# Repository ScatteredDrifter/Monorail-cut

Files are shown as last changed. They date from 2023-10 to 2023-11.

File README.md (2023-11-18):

# Monorail V2

This board adapts the original **Monorail V²** however some fundamental changes were made to fit into a different case by **M4NU**.

## Current status:

>Prototypes were ordered and are functioning. 

- + Encoder works 
- + VIAL firmware works 
- + LED-Backlight works
- - misconfigured stabilizer orientation. This has been fixed in 9eb0997

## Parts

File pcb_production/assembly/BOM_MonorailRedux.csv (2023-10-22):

Comment | Designator | Footprint | LCSC
10u | C1,C2,C4 | Capacitor_SMD:C_0402_1005Metric | C315248
0.1uF | LCSC: C3011705 | C13,C14,C15,C16,C17,C18,C19,C20 | Capacitor_SMD:C_0603_1608Metric | C3011705
1u | C3,C5 | Capacitor_SMD:C_0402_1005Metric | C107372
30p | C6,C27 | Capacitor_SMD:C_0402_1005Metric | C1570
100n | C7,C8,C21,C22,C23,C25,C26,C28 | Capacitor_SMD:C_0402_1005Metric | C60474
BAV70 | D1,D2,D3,D4,D5,D6,D7,D8,D9,D10,D11,D12,D13,D14,D15,D16,D17,D18,D19,D20,D21,D22 | Package_TO_SOT_SMD:SOT-23 | C68978
WS2812B | D59,D60,D61,D62,D63,D64,D65,D66,D67 | WS2812B:WS2812B_data-bridgeable
500mA | F1 | Fuse:Fuse_1206_3216Metric | C69688
MountingHole_Pad | H1 | kicad:Minivan-reference
Conn_01x02_Male | J1,J2,J3 | Connector_PinHeader_2.54mm:PinHeader_1x02_P2.54mm_Vertical
Conn_01x02_Male | J4 | Connector_PinSocket_2.54mm:PinSocket_1x02_P2.54mm_Vertical
USB_C_Receptacle_USB2.0 | J6 | Connector_USB:USB_C_Receptacle_HRO_TYPE-C-31-M-12 | C165948
Conn_01x04_Male | J8 | Connector_PinHeader_2.54mm:PinHeader_1x04_P2.54mm_Vertical
Conn_01x03_Male | J9 | Connector_PinHeader_2.54mm:PinHeader_1x03_P2.54mm_Vertical
SolderJumper_2_Bridged | JP1 | Jumper:SolderJumper-2_P1.3mm_Bridged2Bar_Pad1.0x1.5mm
MX-NoLED | MX1,MX2,MX7,MX8,MX9,MX10,MX11,MX12,MX13,MX14,MX15,MX16,MX17,MX18,MX19,MX20,MX21,MX22,MX23,MX24,MX25,MX26,MX27,MX28,MX29,MX30,MX31,MX32,MX33,MX34,MX35,MX36,MX37,MX38,MX39,MX40,MX41,MX42,MX43,MX45,MX46,MX47,MX48,MX49,MX52,MX53,MX54,MX57,MX58 | marbastlib-mx:SW_MX_HS_1u_NOREF
MX-NoLED | MX3 | marbastlib-mx:SW_MX_1u
1k | R12,R14 | Resistor_SMD:R_0402_1005Metric | C11702
-10k | R13 | Resistor_SMD:R_0603_1608Metric | C98220
5.1k | R2,R4,R5 | Resistor_SMD:R_0603_1608Metric | C23186
27 | R6,R7 | Resistor_SMD:R_0402_1005Metric | C138021
RotaryEncoder_Switch | SW3 | marbastlib-various:ROT_Alps_EC11E-Switch
Conn_01x03_Female | SWD1 | Connector_PinHeader_2.54mm:PinHeader_1x03_P2.54mm_Vertical
SW_SPST | SWR1,SWR2 | Keebio-Parts:SW_SPST_TL3342 | C2886894
SRV05-4 | U1 | Package_TO_SOT_SMD:SOT-23-6 | C85364
XC6206PxxxMR | U2 | Package_TO_SOT_SMD:SOT-23 | C5446
RP2040TR7 | U3 | cipulot_kicad_parts:RP2040-QFN-56 | C2040
W25Q128JVS | U4 | Package_SO:SOIC-8_5.23x5.23mm_P1.27mm | C97521
Crystal_GND24_Small | Y1 | Crystal:Crystal_SMD_3225-4Pin_3.2x2.5mm | C9002

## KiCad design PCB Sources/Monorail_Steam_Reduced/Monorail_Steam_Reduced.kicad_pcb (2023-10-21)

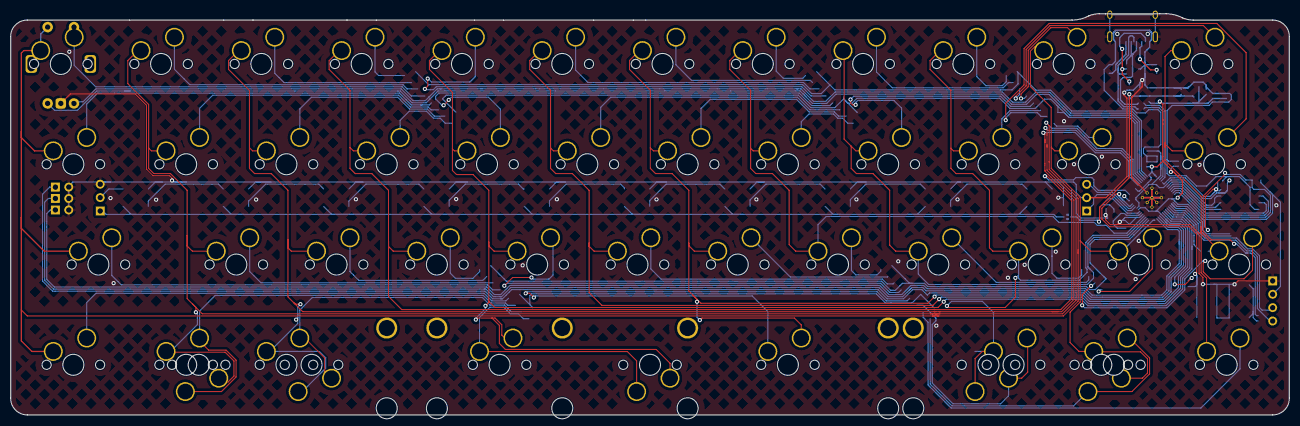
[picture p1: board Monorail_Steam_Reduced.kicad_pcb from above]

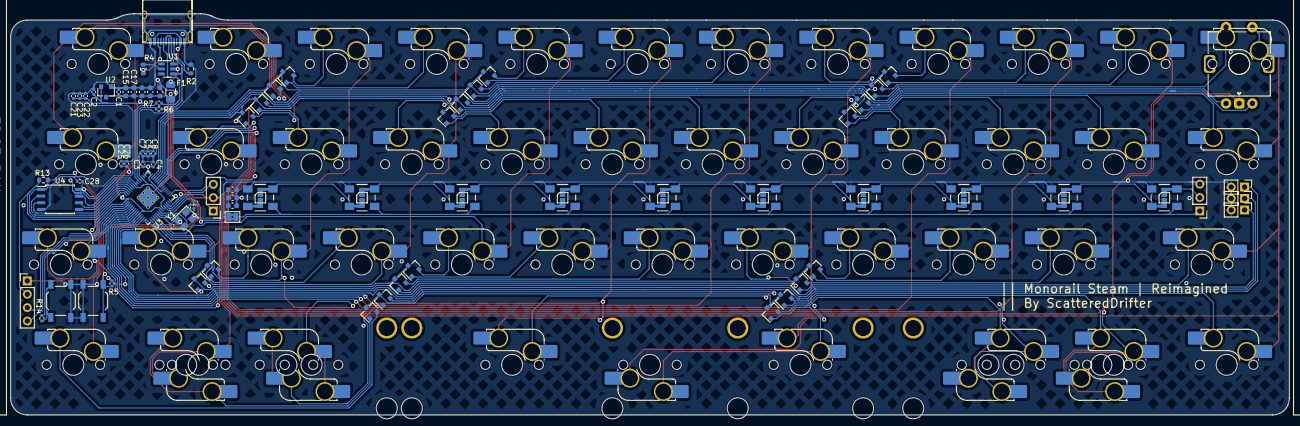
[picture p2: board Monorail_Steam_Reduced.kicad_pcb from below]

Board: 2 copper layers, 242.9 x 76.2 mm, 129 parts (129 on the bottom side), 102 nets.

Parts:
C1, C2, C4: 10u; C_0402_1005Metric
C3, C5: 1u; C_0402_1005Metric
C6, C27: 30p; C_0402_1005Metric
C7, C8, C21, C22, C23, C25, C26, C28: 100n; C_0402_1005Metric
C13, C14, C15, C16, C17, C18, C19, C20: 0.1uF; C_0603_1608Metric
D1, D2, D3, D4, D5, D6, D7, D8, D9, D10, D11, D12, D13, D14, D15, D16, D17, D18, D19, D20, D21, D22: BAV70; SOT-23
D56, D59, D60, D61, D62, D63, D64, D65, D66, D67: WS2812B; WS2812B_data-bridgeable
F1: 500mA; Fuse_1206_3216Metric
J1, J2, J3: Conn_01x02_Male; PinHeader_1x02_P2.54mm_Vertical
J6: USB_C_Receptacle_USB2.0; USB_C_Receptacle_HRO_TYPE-C-31-M-12
J8: Conn_01x04_Male; PinHeader_1x04_P2.54mm_Vertical
J9: Conn_01x03_Male; PinHeader_1x03_P2.54mm_Vertical
JP1: SolderJumper_2_Bridged; SolderJumper-2_P1.3mm_Bridged2Bar_Pad1.0x1.5mm
MX1, MX2, MX7, MX8, MX9, MX10, MX11, MX12, MX13, MX14, MX15, MX16, MX17, MX18, MX19, MX20, MX21, MX22, MX23, MX24, MX25, MX26, MX27, MX28, MX29, MX30, MX31, MX32, MX33, MX34, MX35, MX36, MX37, MX38, MX39, MX40, MX41, MX42, MX43, MX45, MX46, MX47, MX48, MX49, MX52, MX53, MX54, MX57, MX58: MX-NoLED; SW_MX_HS_1u_NOREF
R2, R4: 5.1k; R_0603_1608Metric
R5: 5.1k; R_0402_1005Metric
R6, R7: 27; R_0402_1005Metric
R12, R14: 1k; R_0402_1005Metric
R13: -10k; R_0603_1608Metric
SW3: RotaryEncoder_Switch; ROT_Alps_EC11E-Switch
SWD1: Conn_01x03_Female; PinHeader_1x03_P2.54mm_Vertical
SWR1, SWR2: SW_SPST; SW_SPST_TL3342
U1: SRV05-4; SOT-23-6
U2: XC6206PxxxMR; SOT-23
U3: RP2040TR7; RP2040-QFN-56
U4: W25Q128JVS; SOIC-8_5.23x5.23mm_P1.27mm
Y1: Crystal_GND24_Small; Crystal_SMD_3225-4Pin_3.2x2.5mm

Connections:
+1V1: C5.1, C7.1, C8.1, U3.23 (DVDD), U3.45 (VREG_VOUT), U3.50 (DVDD)
+3V3: C2.1, C3.1, C4.1, C21.1, C22.1, C23.1, C25.1, C26.1, C28.1, J8.2, R5.1, R13.1, U2.2 (VO), U3.1 (IOVDD), U3.10 (IOVDD), U3.22 (IOVDD), U3.33 (IOVDD), U3.42 (IOVDD), U3.43 (ADC_AVDD), U3.44 (VREG_VIN), U3.48 (USB_VDD), U3.49 (IOVDD), U4.8 (VCC)
+5V: C1.1, C13.1, C14.1, C15.1, C16.1, C17.1, C18.1, C19.1, C20.1, F1.1, JP1.1 (A), U2.3 (VI)
+5VD: D56.1 (VDD), D59.1 (VDD), D60.1 (VDD), D61.1 (VDD), D62.1 (VDD), D63.1 (VDD), D64.1 (VDD), D65.1 (VDD), D66.1 (VDD), D67.1 (VDD), J9.1, JP1.2 (B)
COL0: MX7.1 (COL), MX19.1 (COL), MX31.1 (COL), MX46.1 (COL), SW3.S1, U3.37 (GPIO25)
COL1: MX2.1 (COL), MX8.1 (COL), MX20.1 (COL), MX32.1 (COL), MX52.1 (COL), U3.36 (GPIO24)
COL2: MX9.1 (COL), MX21.1 (COL), MX33.1 (COL), MX47.1 (COL), MX53.2 (ROW), U3.35 (GPIO23)
COL3: MX10.1 (COL), MX22.1 (COL), MX34.1 (COL), U3.29 (GPIO18)
COL4: MX11.1 (COL), MX23.1 (COL), MX35.1 (COL), MX43.1 (COL), MX45.2 (ROW), U3.7 (GPIO5)
COL5: MX12.1 (COL), MX24.1 (COL), MX36.1 (COL), U3.8 (GPIO6)
COL6: MX13.1 (COL), MX25.1 (COL), MX37.1 (COL), MX58.2 (ROW), U3.9 (GPIO7)
COL7: MX14.1 (COL), MX26.1 (COL), MX38.1 (COL), U3.18 (GPIO15)
COL8: MX15.1 (COL), MX27.1 (COL), MX39.1 (COL), U3.16 (GPIO13)
COL9: MX16.1 (COL), MX28.1 (COL), MX40.1 (COL), MX49.2 (ROW), MX54.1 (COL), U3.17 (GPIO14)
COL10: MX1.1 (COL), MX17.1 (COL), MX29.1 (COL), MX41.1 (COL), MX57.1 (COL), U3.14 (GPIO11)
COL11: MX18.1 (COL), MX30.1 (COL), MX42.1 (COL), MX48.1 (COL), U3.6 (GPIO4)
D+: J6.A6 (D+), J6.B6 (D+), R7.2, U1.6 (IO4)
D-: J6.A7 (D-), J6.B7 (D-), R6.2, U1.4 (IO3)
ENCA: SW3.B, U3.39 (GPIO27/ADC1)
ENCB: SW3.A, U3.40 (GPIO28/ADC2)
ENC_ROW: D1.1 (A), MX7.2 (ROW), SW3.S2
GND: C1.2, C2.2, C3.2, C4.2, C5.2, C6.1, C7.2, C8.2, C13.2, C14.2, C15.2, C16.2, C17.2, C18.2, C19.2, C20.2, C21.2, C22.2, C23.2, C25.2, C26.2, C27.2, C28.2, D56.3 (VSS), D59.3 (VSS), D60.3 (VSS), D61.3 (VSS), D62.3 (VSS), D63.3 (VSS), D64.3 (VSS), D65.3 (VSS), D66.3 (VSS), D67.3 (VSS), J1.2, J2.2, J3.2, J6.A1 (GND), J6.A12 (GND), J6.B1 (GND), J6.B12 (GND), J6.S1 (SHIELD), J8.1, J9.3, R2.1, R4.1, SW3.C, SWD1.2, SWR1.1 (A), SWR2.1 (A), U1.2 (VN), U2.1 (GND), U3.19 (TESTEN), U3.57 (GND), U4.4 (GND), Y1.2, Y1.4
LED1: J1.1, U3.13 (GPIO10)
LED2: J2.1, U3.11 (GPIO8)
LED3: J3.1, U3.12 (GPIO9)
unnamed: C6.2, R12.1, Y1.1
unnamed: D56.4 (DIN), D64.2 (DOUT)
unnamed: D59.2 (DOUT), D60.4 (DIN)
unnamed: D60.2 (DOUT), D61.4 (DIN)
unnamed: D61.2 (DOUT), D62.4 (DIN)
unnamed: D62.2 (DOUT), D63.4 (DIN)
unnamed: D63.2 (DOUT), D67.4 (DIN)
unnamed: D64.4 (DIN), D65.2 (DOUT)
unnamed: D65.4 (DIN), D66.2 (DOUT)
unnamed: D66.4 (DIN), D67.2 (DOUT)
unnamed: J6.A5 (CC1), R2.2
unnamed: J6.B5 (CC2), R4.2
unnamed: D21.1 (A), MX1.2 (ROW), MX57.2 (ROW)
unnamed: D19.1 (A), MX2.2 (ROW), MX52.2 (ROW)
unnamed: D1.2 (A), MX8.2 (ROW)
unnamed: D2.1 (A), MX9.2 (ROW)
unnamed: D2.2 (A), MX10.2 (ROW)
unnamed: D3.1 (A), MX11.2 (ROW)
unnamed: D3.2 (A), MX12.2 (ROW)
unnamed: D4.1 (A), MX13.2 (ROW)
unnamed: D4.2 (A), MX14.2 (ROW)
unnamed: D5.1 (A), MX15.2 (ROW)
unnamed: D5.2 (A), MX16.2 (ROW)
unnamed: D6.1 (A), MX17.2 (ROW)
unnamed: D6.2 (A), MX18.2 (ROW)
unnamed: D7.2 (A), MX19.2 (ROW)
unnamed: D7.1 (A), MX20.2 (ROW)
unnamed: D8.2 (A), MX21.2 (ROW)
unnamed: D8.1 (A), MX22.2 (ROW)
unnamed: D13.2 (A), MX23.2 (ROW)
unnamed: D13.1 (A), MX24.2 (ROW)
unnamed: D14.2 (A), MX25.2 (ROW)
unnamed: D14.1 (A), MX26.2 (ROW)
unnamed: D15.2 (A), MX27.2 (ROW)
unnamed: D15.1 (A), MX28.2 (ROW)
unnamed: D18.1 (A), MX29.2 (ROW)
unnamed: D18.2 (A), MX30.2 (ROW)
unnamed: D9.1 (A), MX31.2 (ROW)
unnamed: D9.2 (A), MX32.2 (ROW)
unnamed: D10.1 (A), MX33.2 (ROW)
unnamed: D10.2 (A), MX34.2 (ROW)
unnamed: D11.1 (A), MX35.2 (ROW)
unnamed: D11.2 (A), MX36.2 (ROW)
unnamed: D12.1 (A), MX37.2 (ROW)
unnamed: D12.2 (A), MX38.2 (ROW)
unnamed: D16.1 (A), MX39.2 (ROW)
unnamed: D16.2 (A), MX40.2 (ROW)
unnamed: D17.1 (A), MX41.2 (ROW)
unnamed: D17.2 (A), MX42.2 (ROW)
unnamed: D20.1 (A), MX43.2 (ROW), MX45.1 (COL)
unnamed: D19.2 (A), MX46.2 (ROW)
unnamed: D20.2 (A), MX47.2 (ROW), MX53.1 (COL)
unnamed: D21.2 (A), MX48.2 (ROW)
unnamed: D22.1 (A), MX49.1 (COL), MX54.2 (ROW)
unnamed: D22.2 (A), MX58.1 (COL)
unnamed: R14.2, SWR2.2 (B)
unnamed: R6.1, U3.46 (USB_DM)
unnamed: R7.1, U3.47 (USB_DP)
QSPI_CLK: U3.52 (QSPI_SCLK), U4.6 (CLK)
QSPI_D0: U3.53 (QSPI_SD0), U4.5 (DI(IO0))
QSPI_D1: U3.55 (QSPI_SD1), U4.2 (DO(IO1))
QSPI_D2: U3.54 (QSPI_SD2), U4.3 (IO2)
QSPI_D3: U3.51 (QSPI_SD3), U4.7 (IO3)
QSPI_SS: R13.2, R14.1, U3.56 (QSPI_SS_N), U4.1 (~CS)
RGB_OUT: D56.2 (DOUT), J9.2
ROW0: D1.3 (K), D2.3 (K), D3.3 (K), D4.3 (K), D5.3 (K), D6.3 (K), U3.41 (GPIO29/ADC3)
ROW1: D7.3 (K), D8.3 (K), D13.3 (K), D14.3 (K), D15.3 (K), D18.3 (K), U3.38 (GPIO26/ADC0)
ROW2: D9.3 (K), D10.3 (K), D11.3 (K), D12.3 (K), D16.3 (K), D17.3 (K), U3.15 (GPIO12)
ROW3: D19.3 (K), D20.3 (K), D21.3 (K), D22.3 (K)
RUN: R5.2, SWR1.2 (B), U3.26 (RUN)
SCL: J8.3, U3.4 (GPIO2)
SDA: J8.4, U3.5 (GPIO3)
SWCLK: SWD1.1, U3.24 (SWCLK)
SWDIO: SWD1.3, U3.25 (SWDIO)
VCC: F1.2, J6.A4 (VBUS), J6.A9 (VBUS), J6.B4 (VBUS), J6.B9 (VBUS), U1.5 (VP)
XIN: C27.1, U3.20 (XIN), Y1.3
XOUT: R12.2, U3.21 (XOUT)

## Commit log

2023-10-15 updated pcb: deleted num-row, new bottom row
    [Monorail_Steam_Reduced.kicad_sch]
2023-10-15 removed unecessary files, cleaned pcb
    [Diesel_2.0_BOM.csv, Diesel_2.0_BOM_OLD.csv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]
2023-10-15 updated positions, readme, deleted unecessary files
    [Hull_V4N_Tray_Base.step, Hull_V4N_Tray_Plate.step, Monorail_Steam_Reduced.kicad_pcb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]
2023-10-18 set initial positions for components
    [Monorail_Steam_Reduced.kicad_pcb, Monorail_Steam_Reduced.kicad_sch]
2023-10-19 began routing upper portion, improved placement
    [Monorail_Steam_Reduced.kicad_pcb, Monorail_Steam_Reduced.kicad_sch]
2023-10-21 updated routing, position of diodes
    [Monorail_Steam_Reduced.kicad_pcb, Monorail_Steam_Reduced.kicad_sch]
2023-10-21 finished base routing
    [Monorail_Steam_Reduced.kicad_pcb, Monorail_Steam_Reduced.kicad_sch]
2023-10-21 added mounting holes
2023-10-22 added silkscreen, finalized position and routing
    [Monorail_Steam_Reduced.kicad_sch]
2023-10-22 finalized silkscreen and fixed positions
    [Monorail_Steam_Reduced.kicad_sch]
2023-10-22 version¹, updated production files, gerber, dir structure
    [BOM_MonorailRedux.csv, Combined Coriander.dxf, Combined Hull.dxf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]
2023-10-24 fixed overlapping nets near encoder, updated gerber
    [Monorail_Steam_Reduced-B_Cu.gbl, Monorail_Steam_Reduced-B_Mask.gbs, Monorail_Steam_Reduced-B_Paste.gbp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]
2023-11-18 fix bottom row stabilizer orientation
    [Monorail_Steam_Reduced.kicad_sch]
2023-11-18 update README, add prototype information
